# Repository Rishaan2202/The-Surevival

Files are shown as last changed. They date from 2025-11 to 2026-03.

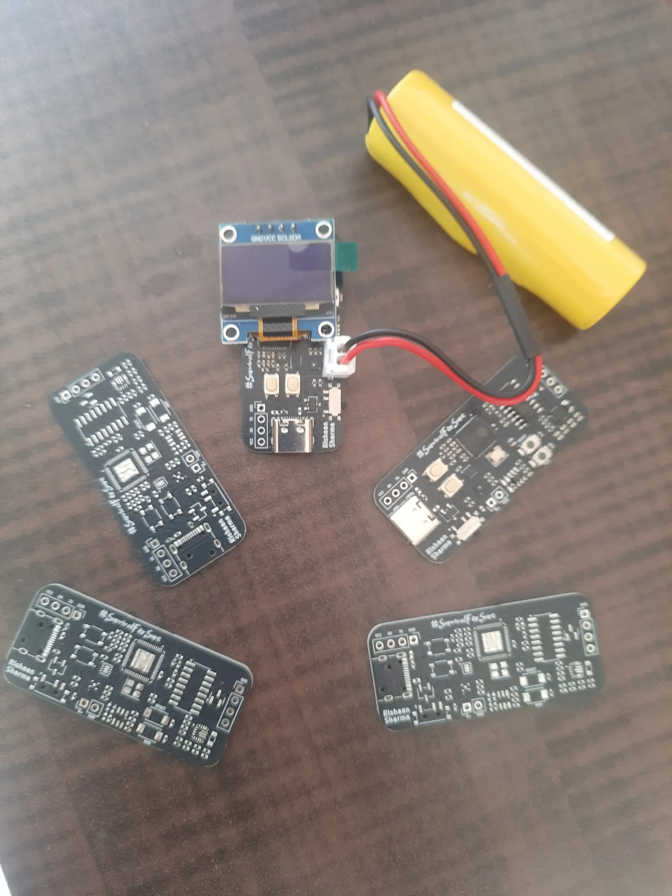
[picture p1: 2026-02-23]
20251218_154922.webp

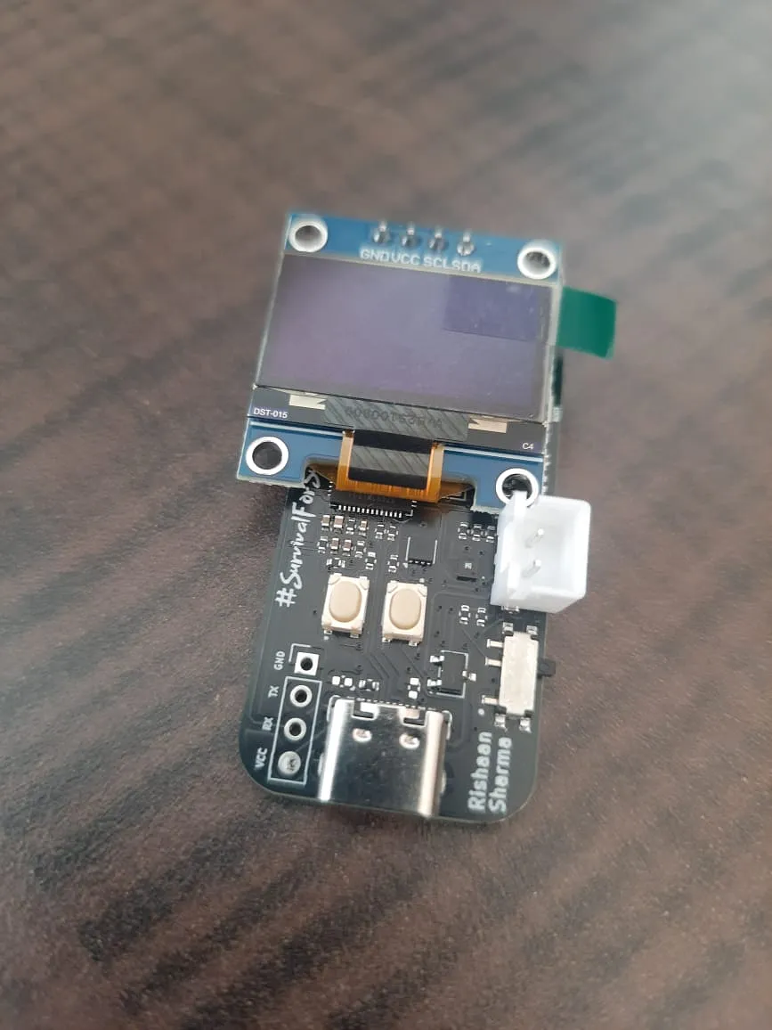
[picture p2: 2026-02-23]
image.webp

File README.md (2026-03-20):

# The-Surevival

<h2> Intro!!! </h2>
Yooo there!!! I am Rishaan Sharma, a 14 year old Indian. I made this project, 'The Surevival' as a project in hcb!
<br>
I have made this on KiCad, and yeah I'm a beginner! It's a very interesting project, which was attained after repetitive feilures, so please do check out for the Journal to know all that in detail!

<h2>OVERVIEW 🤔</h2>
So this is gonna be a project on a PCB, which is a PCBA (Yeah, cause I don't even have a soldering iron!), and yeah, It's my first PCB!!! It is basically a tool whose name suggests that it's a 'Survival Tool' (Sure + Survival = SUREVIVAL). Yeah, cool name rigth, ik! This is supposed to have a few features which are listed below! I have used the ESP32-S3FN8 as the MCU! and am having a Type-C input which is just for charging the battery! The 2000mAh Li-ion battery is gonna power up all the stuff like the load sensor, temp. sensor etc... So yeah, It's a cool thing and now take a look at it's features!!!

<h2>FEATURES ⚡️</h2>
1) GPS Tracking 
<br>
2) No. of Survival Dayzzz prediction using food! (My favorite)
<br>
3) Weather Monitoring
<br>
4) OLED Display!!! (For better UI)

<h2> THE SCHEMATIC </h2>

[The Surevival (2).pdf](https://github.com/user-attachments/files/23728820/The.Surevival.2.pdf)

<h3>It consists of 4 units, and These units further contain subunits which are lister below:</h3>
<br>

<h3>1) MCU!!! </h3>
<br>

<h3> 2) Power Management: </h3>
- Input Processing Unit (IPU) <br>
- Buck-Boost converter <br>
- Battery Charging Unit (BCU)
<br>

<h3> 3) Peripherals: </h3>
-Load Sensing Unit (Weight Sensor) <br>
- Switches (UI bro!) <br>
- GPS (ofc.) <br>
- Weather Monitoring Unit (WMU) <br>
- Display (OLED)
<br>

<h3>4) Crystal!</h3>
<br>

<h2>THE PCB</h2>

<h3> SO this is all the placement and routing stuff! It was really Time-Consuming!!! </h3>


<br>

<h3> idts that I need to explain a lot about the PCB, but yeah, I must compliment it's compactness, cause it's just 23mm*51mm </h3>
<br>
<br>

<h2>THE 3D Look (My fav!)</h2>

<h3> So yeah, I kinda like this part, cause it shows how would it be looking when it comes outside the screen (im in real world)! </h3>

<h3> Let's take a look at the one without much of the components, but with the OLED, which was placed by me on KiCad! </h3>


<br>


<br>

<h3> Now, let's see the one with all the components on it except the OLED and the GPS, which was produced by JLCPCB! </h3>
<br>



<h3> Yeah, that's so cool! I can't even believe that I made that! </h3>
<br>
<br>

<h2>THE BOM</h2>

<h3> Hmmm, so here is the tricky part! It took me many days to make this thing! I also tried to add a soldering kit to this, as I need that to put a few components on this, but then I came to know that I can't do that , so I removed that and now the BOM is $86.28 (JLCPCB) + $13.52 (Robocraze). Yeah I have 2 suppliers, one for PCBA and the other for some extra components which has $0 as it is originally from INDIA (As I am!) </h3>
<br>



<h3> Well, this doesn't contain the price of the PCBA products, but that will be clear by looking at this </h3>
<br>


<br>
<br>

<h2>Images</h2>
<br>
<h3>
  
  <br>
  
  <br>
  
  <br>
  
  <br>
</h3>

<h2>OUTRO!!!</h2>
<br>

Yeah, so this was the first PCB built by me, I have already made one before, but because of some unignorable things, I will need to redesign it. Well if you want to give any kinda comment regarding this project, then pls feel free to contact me. Here are my details:
<br>

Slack Username (Hackclub Workflow): @Rishaan
<br>
Email: rishaan.sharma2202@gmail.com

Pls don't forget to take a look at the journals! And also pls visit and follow this project on Blueprint here:
<br>

https://blueprint.hackclub.com/projects/210
<br>
<h2> TYSM 😊🙏 </h2>

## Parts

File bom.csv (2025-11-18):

Designator | Footprint | Quantity | Value | LCSC Part # | Robocraze | Value (in USD)
C1, C2 | 402 | 2 | 10pF | C32949
C12, C13, C14, C16, C25, C7 | 402 | 6 | 0.1uF | C1525
C15, C27, C28, C29 | 402 | 4 | 22uF | C105226
C17, C18, C19, C8 | 402 | 4 | 1uF | C52923
C23 | 402 | 1 | 4.7uF | C23733
C24, C26, C30, C31, C32, C6 | 402 | 6 | 10uF | C15525
D1, D2, D3 | 402 | 3 | LED | C30584803
IC1 | HSFPAR004A | 1 | HSFPAR004A | C470800
J1 | PinHeader_1x02_P2.54mm_Vertical_JST | 1 | Battery Connectors |  | 2.54mm pitch 2 pin JST Cable with Connector | 0.73
J2, J3 | PinHeader_1x04_P2.54mm_Vertical_Female | 1 | Conn_01x04 |  | 40x1 Female Berg Strip | 0.1
J5 | AMPHENOL_10155435-00011LF | 1 | USB Type-C Input | C2765186
L1 | 805 | 1 | 1.5uH | C216155
Q1 | SOT-23 | 1 | SS8550 | C727138
R1 | 402 | 1 | 220Ω | C25091
R10, R12 | 402 | 2 | 1kΩ | C11702
R11 | 402 | 1 | 2kΩ | C4109
R14, R21 | 402 | 2 | 100kΩ | C25741
R15 | 402 | 1 | 470kΩ | C427225
R16 | 402 | 1 | 150kΩ | C2909320
R17, R24, R25, R30, R31, R32, R33, R34, R35, R36, R37 | 402 | 11 | 10kΩ | C25744
R2, R3 | 402 | 2 | 5kΩ | C5948099
R20 | 402 | 1 | 100Ω | C25076
R26, R27 | 402 | 2 | 22Ω | C25092
R28, R29 | 402 | 2 | 5.1kΩ | C25905
R5, R6, R8, R9 | 402 | 4 | 4.7kΩ | C25900
S1, S2 | SW_SKRPACE010 | 2 | SKRPACE010 | C139797
S3, S4 | Push Button | 2 | TS-1088-AR02016 | C720477
SW1 | SW_PCM12SMTR | 1 | PCM12SMTR | C221841
U1 | SOT-23-3L_AOS | 1 | AO3401A | C15127
U10 | VREG_TPS63070RNMR | 1 | TPS63070RNMR | C109322
U3 | WSON-8-1EP_2x2mm_P0.5mm_EP0.9x1.6mm_ThermalVias | 1 | TMP1075DSG | C2870250
U4 | ESP32-S3FN8 | 1 | ESP32-S3FN8 | C2913196
U5 | Crystal_SMD_3225-4Pin_3.2x2.5mm | 1 | SMD3225 | C5444549
U6 | SOP-16_3.9x9.9mm_P1.27mm | 1 | HX711 | C6705483
U9 | SOT23-6 | 1 | TP4057 | C725791
J6 | PinHeader_1x04_P2.54mm_Vertical_Male | 1 |  |  | 40x1 Pin 2.54mm Pitch Male Berg Strip | 0.056
Display1 | OLED Display | 1 |  |  | 0.96 Inch OLED Display Module SPI/I2C 4pin Blue Color | 3.52
GPS1 | GPS | 1 |  |  | Ublox Neo-6M GPS Module With EEPROM | 5.39
B1 | Li-ion Battery | 1 | Battery |  | Witty Fox 3.7V 2000 mAh Li-ion GPS Cylindrical Battery | 3.41
 |  |  |  |  |  | 13.206

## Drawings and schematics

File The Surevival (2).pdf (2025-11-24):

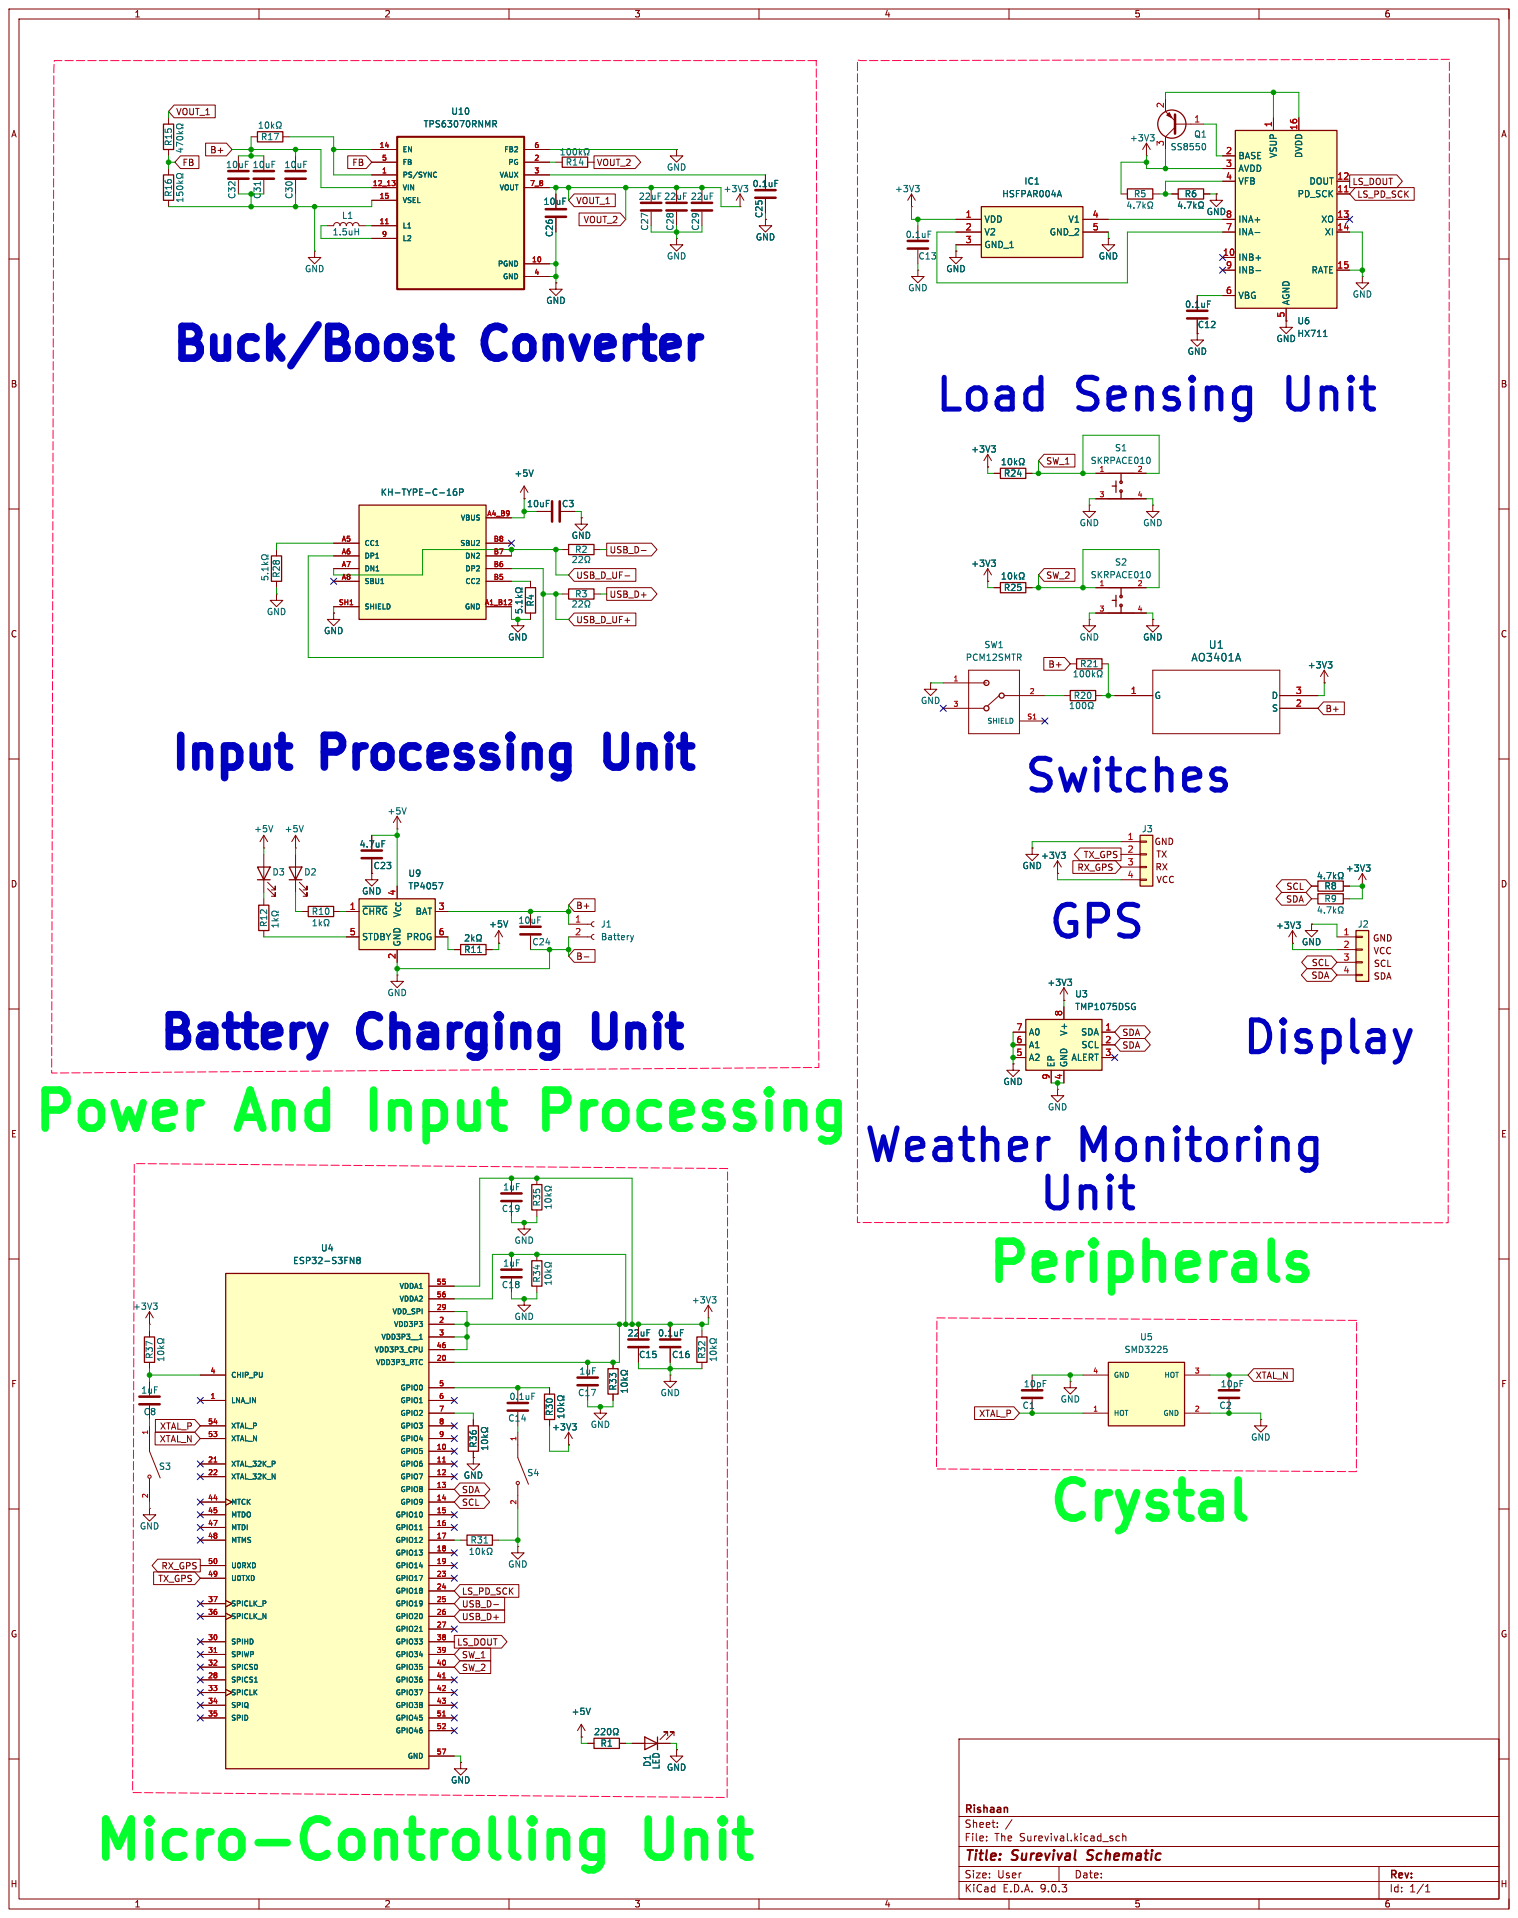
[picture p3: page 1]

5 DVDD 16 DOUT 12 PD_SCK 11 XO 13 XI 14 RATE 15 GND GND

5 DVDD 16 DOUT 12 PD_SCK 11 XO 13 XI 14 RATE 15 U6 HX711 +3V3

4 SDA 1 SCL 2 ALERT 3 +3V3 GND GND

2 BAT 3 PROG 6 U9 TP4057 GND R12 þÿ1k©

4 SDA 1 SCL 2 ALERT 3 U3 TMP1075DSG R30 C14 þÿ10k© 0.1uF

Battery Charging Unit
Power And Input Processing

Id: 1/1 Title: Surevival Schematic

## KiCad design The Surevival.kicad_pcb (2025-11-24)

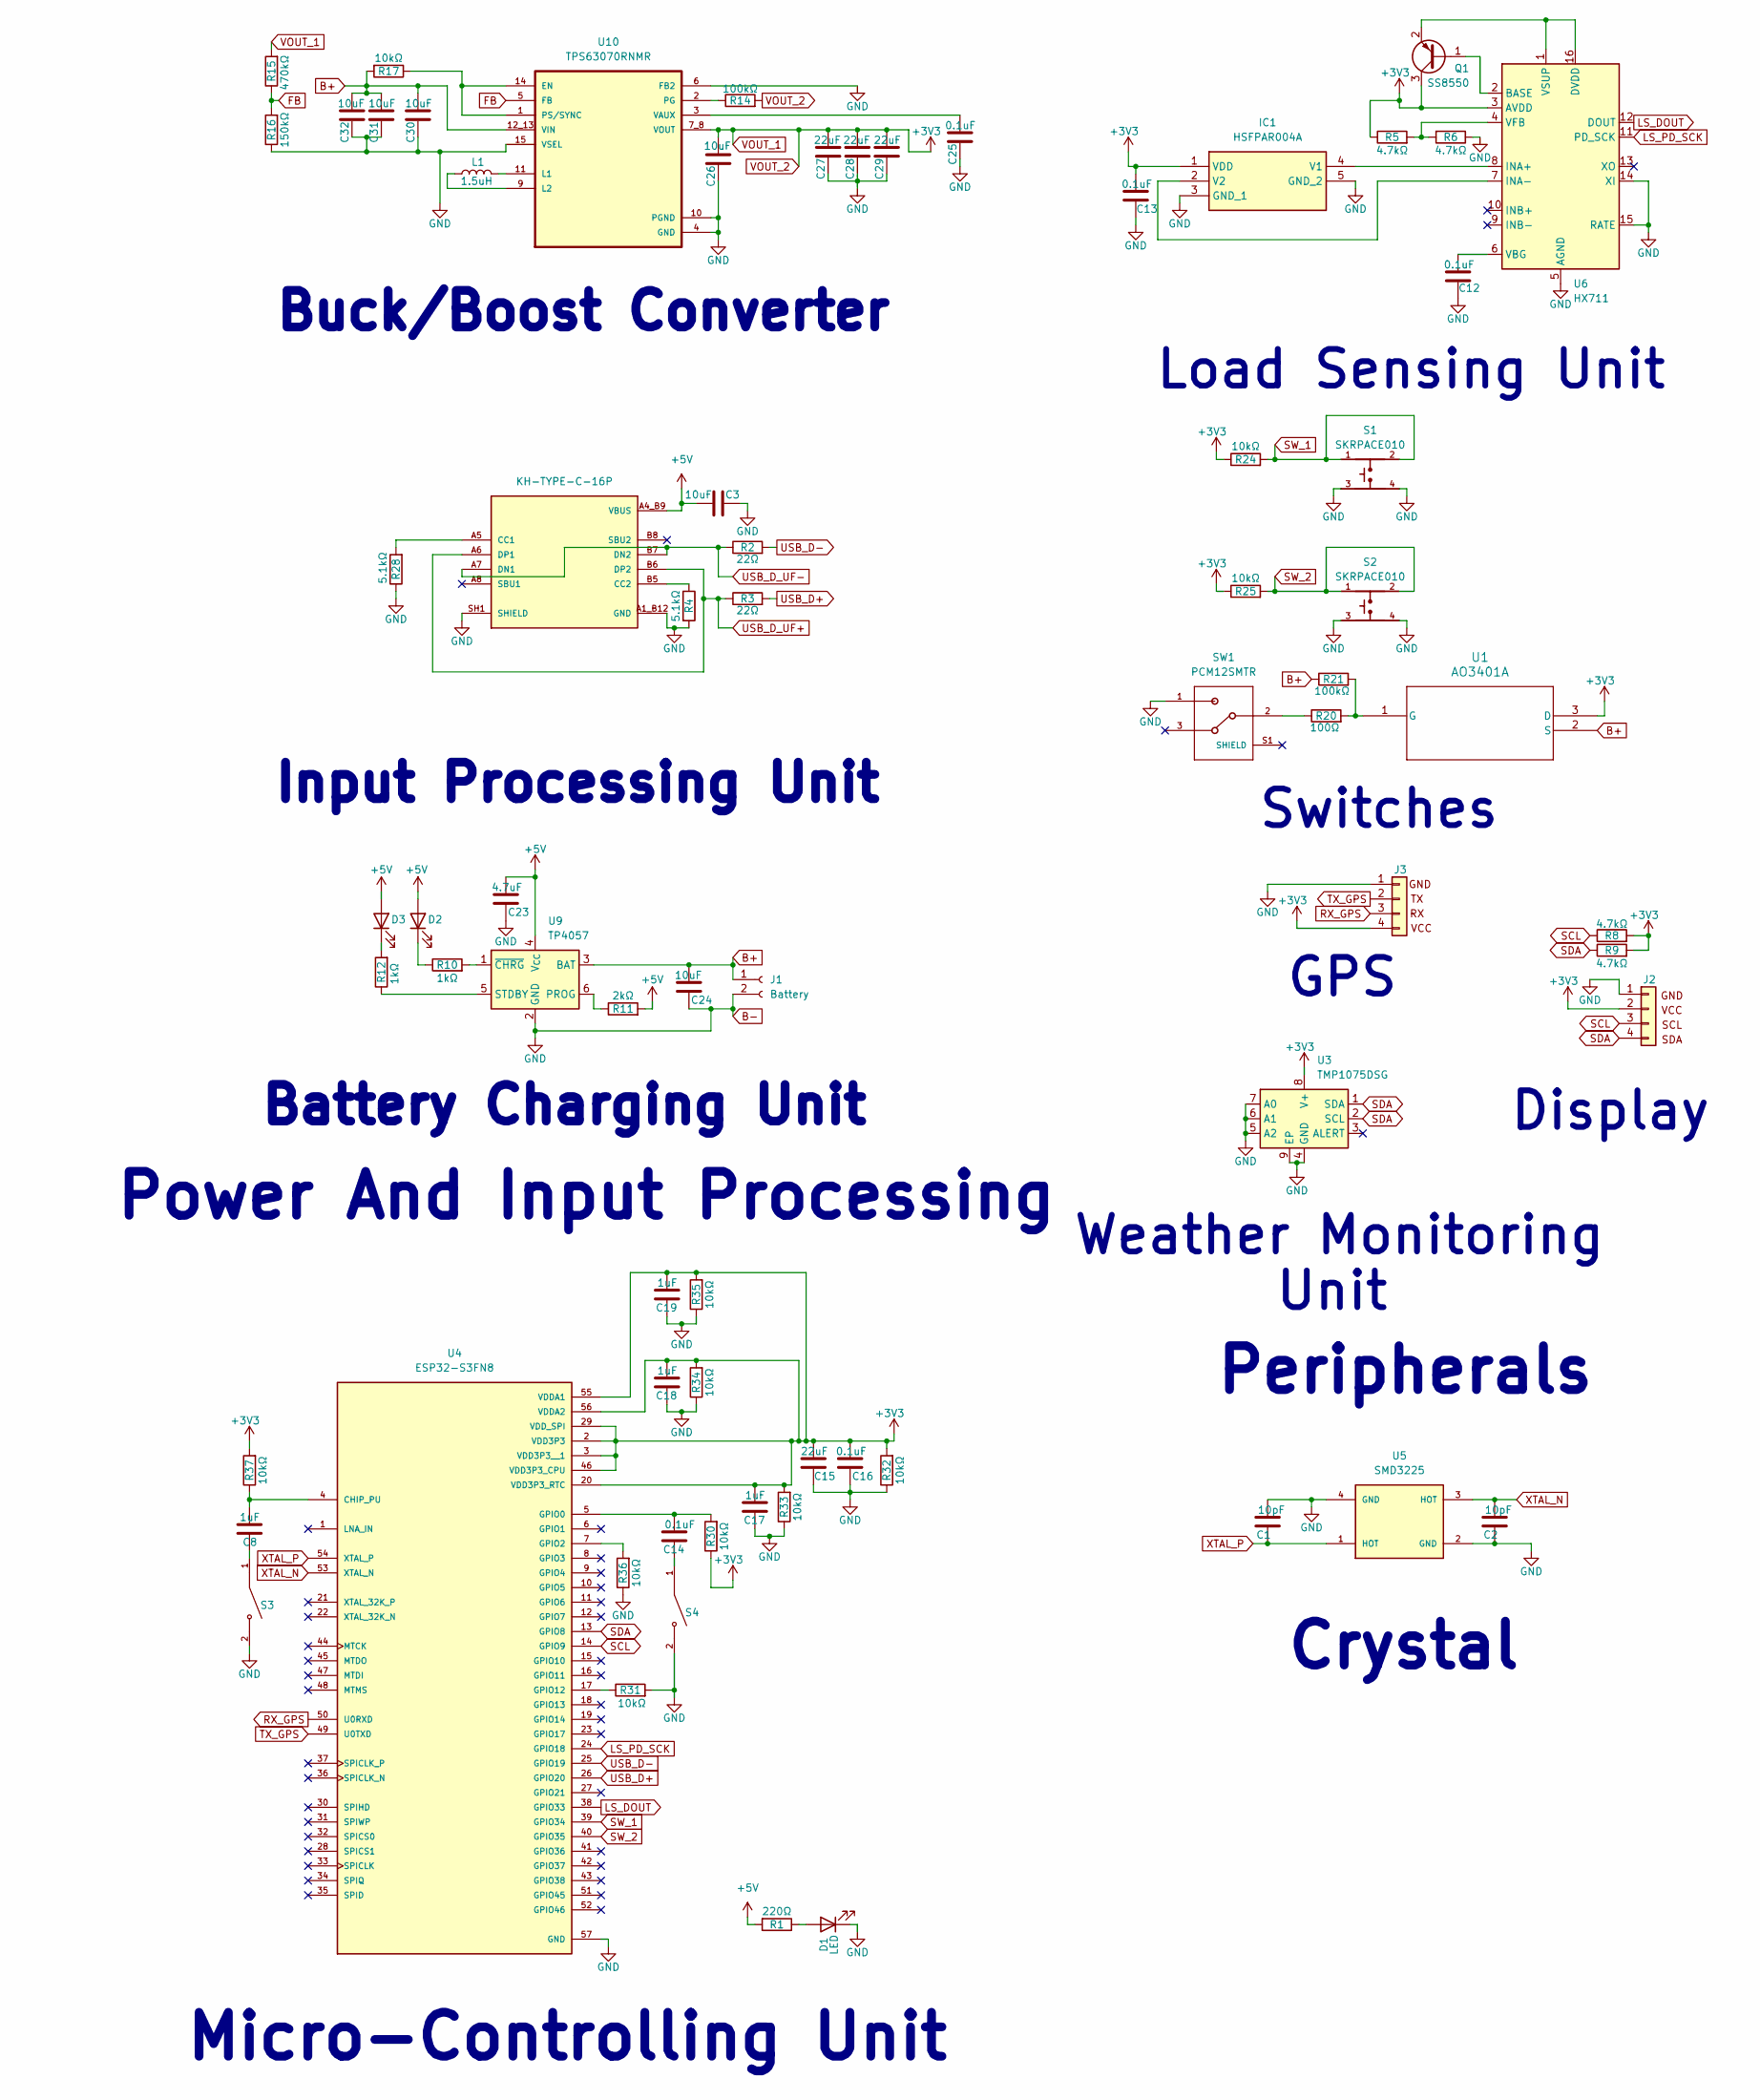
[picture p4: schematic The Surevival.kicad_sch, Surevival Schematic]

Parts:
C1, C2: 10pF; C_0402_1005Metric
C3, C24, C26, C30, C31, C32: 10uF; C_0402_1005Metric
C8, C17, C18, C19: 1uF; C_0402_1005Metric
C12, C13, C14, C16, C25: 0.1uF; C_0402_1005Metric
C15, C27, C28, C29: 22uF; C_0402_1005Metric
C23: 4.7uF; C_0402_1005Metric
D1, D2, D3: LED; LED_0402_1005Metric
IC1: HSFPAR004A; Mouser Part Number 688-HSFPAR004A
J1: Battery; PinHeader_1x02_P2.54mm_Vertical
J2, J3: Conn_01x04; PinHeader_1x04_P2.54mm_Vertical
J6: KH-TYPE-C-16P; KINGHELM_KH-TYPE-C-16P; PARTREV A0
L1: 1.5uH; L_0805_2012Metric
Q1: SS8550; SOT-23
R1: 220Ω; R_0402_1005Metric
R2, R3: 22Ω; R_0402_1005Metric
R4, R28: 5.1kΩ; R_0402_1005Metric
R5, R6, R8, R9: 4.7kΩ; R_0402_1005Metric
R10, R12: 1kΩ; R_0402_1005Metric
R11: 2kΩ; R_0402_1005Metric
R14, R21: 100kΩ; R_0402_1005Metric
R15: 470kΩ; R_0402_1005Metric
R16: 150kΩ; R_0402_1005Metric
R17, R24, R25, R30, R31, R32, R33, R34, R35, R36, R37: 10kΩ; R_0402_1005Metric
R20: 100Ω; R_0402_1005Metric
S1, S2: SKRPACE010; SW_SKRPACE010
S3, S4: TS-1088-AR02016; Push Button; PARTREV N/A
SW1: PCM12SMTR; SW_PCM12SMTR
U1: AO3401A; SOT-23-3L_AOS
U3: TMP1075DSG; WSON-8-1EP_2x2mm_P0.5mm_EP0.9x1.6mm_ThermalVias
U4: ESP32-S3FN8
U5: SMD3225; Crystal_SMD_3225-4Pin_3.2x2.5mm
U6: HX711; SOP-16_3.9x9.9mm_P1.27mm
U9: TP4057; SOT23-6
U10: TPS63070RNMR; VREG_TPS63070RNMR

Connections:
+5V: C3.1, C23.1, D2.2 (A), D3.2 (A), J6.A4_B9 (VBUS), J6.A9_B4 (VBUS), R1.2, R11.2, U9.4 (V_{CC})
B+: C24.1, C30.2, C31.2, C32.2, J1.1, R17.2, R21.1, U1.2 (S), U9.3 (BAT), U10.12_13 (VIN)
B-: C1.1, C2.2, C3.2, C12.2, C13.2, C15.2, C16.2, C17.2, C18.2, C19.2, C23.2, C24.2, C25.1, C26.1, C27.1, C28.1, C29.1, C30.1, C31.1, C32.1, D1.1 (K), IC1.3 (GND_1), IC1.5 (GND_2), J1.2, J2.1, J3.1, J6.A1_B12 (GND), J6.A12_B1 (GND), J6.SH1 (SHIELD), J6.SH2 (SHIELD), J6.SH3 (SHIELD), J6.SH4 (SHIELD), R4.2, R6.1, R16.1, R28.1, R31.2, R32.1, R33.1, R34.1, R35.1, R36.1, S1.3, S1.4, S2.3, S2.4, S3.2, S4.2, SW1.1, U3.4 (GND), U3.5 (A2), U3.6 (A1), U3.7 (A0), U3.9 (EP), U4.57 (GND), U5.2 (GND), U5.4 (GND), U6.5 (AGND), U6.14 (XI), U6.15 (RATE), U9.2 (GND), U10.4 (GND), U10.6 (FB2), U10.10 (PGND), U10.15 (VSEL)
FB: R15.1, R16.2, U10.5 (FB)
LS_DOUT: U4.38 (GPIO33), U6.12 (DOUT)
LS_PD_SCK: U4.24 (GPIO18), U6.11 (PD_SCK)
unnamed: C8.2, S3.1
unnamed: C14.2, S4.1
unnamed: D1.2 (A), R1.1
unnamed: D2.1 (K), R10.1
unnamed: D3.1 (K), R12.2
unnamed: IC1.4 (V1), U6.8 (INA+)
unnamed: IC1.2 (V2), U6.7 (INA-)
unnamed: J6.A5 (CC1), R28.2
unnamed: J6.B5 (CC2), R4.1
unnamed: Q1.1 (B), U6.2 (BASE)
unnamed: Q1.2 (E), U6.1 (VSUP), U6.16 (DVDD)
unnamed: R20.1, SW1.2
unnamed: R20.2, R21.2, U1.1 (G)
unnamed: C8.1, R37.1, U4.4 (CHIP_PU)
unnamed: C14.1, R30.2, U4.5 (GPIO0)
unnamed: R36.2, U4.7 (GPIO2)
unnamed: R31.1, U4.17 (GPIO12)
unnamed: C12.1, U6.6 (VBG)
unnamed: R5.2, R6.2, U6.4 (VFB)
unnamed: R11.1, U9.6 (PROG)
unnamed: R12.1, U9.5 (STDBY)
unnamed: R10.2, U9.1 (~CHRG)
unnamed: R17.1, U10.1 (PS/SYNC), U10.14 (EN)
unnamed: L1.2, U10.11 (L1)
unnamed: L1.1, U10.9 (L2)
unnamed: R14.1, U10.2 (PG)
unnamed: C25.2, U10.3 (VAUX)
RX_GPS: J3.3, U4.50 (U0RXD)
SCL: J2.3, R8.1, U4.14 (GPIO9)
SDA: J2.4, R9.1, U3.1 (SDA), U3.2 (SCL), U4.13 (GPIO8)
SW_1: R24.2, S1.1, S1.2, U4.39 (GPIO34)
SW_2: R25.2, S2.1, S2.2, U4.40 (GPIO35)
TX_GPS: J3.2, U4.49 (U0TXD)
USB_D+: R3.2, U4.26 (GPIO20)
USB_D-: R2.2, U4.25 (GPIO19)
USB_D_UF+: J6.A6 (DP1), J6.B6 (DP2), R3.1
USB_D_UF-: J6.A7 (DN1), J6.B7 (DN2), R2.1
VOUT_1: C13.1, C15.1, C16.1, C17.1, C18.1, C19.1, C26.2, C27.2, C28.2, C29.2, IC1.1 (VDD), J2.2, J3.4, Q1.3 (C), R5.1, R8.2, R9.2, R14.2, R15.2, R24.1, R25.1, R30.1, R32.2, R33.2, R34.2, R35.2, R37.2, U1.3 (D), U3.8 (V+), U4.2 (VDD3P3), U4.3 (VDD3P3__1), U4.20 (VDD3P3_RTC), U4.29 (VDD_SPI), U4.46 (VDD3P3_CPU), U4.55 (VDDA1), U4.56 (VDDA2), U6.3 (AVDD), U10.7_8 (VOUT)
XTAL_N: C2.1, U4.53 (XTAL_N), U5.3 (HOT)
XTAL_P: C1.2, U4.54 (XTAL_P), U5.1 (HOT)

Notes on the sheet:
Unit
Switches
Battery Charging Unit
Peripherals
Buck/Boost Converter
GPS
Power And Input Processing
Micro-Controlling Unit
Input Processing Unit
Weather Monitoring
Load Sensing Unit
Display
Crystal

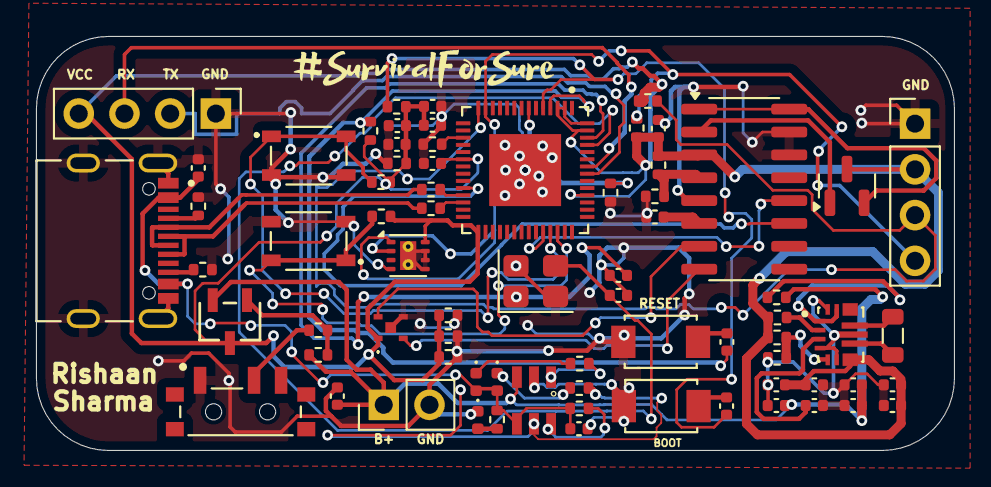
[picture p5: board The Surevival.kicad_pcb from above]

Board: 2 copper layers, 51.0 x 23.0 mm, 72 parts (0 on the bottom side), 46 nets.

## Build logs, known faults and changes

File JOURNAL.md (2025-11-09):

<!--
  ===================    !!READ THIS NOTICE!!   ====================
  DO NOT edit this file manually. Your changes WILL BE OVERWRITTEN!
  This journal is auto generated and updated by Hack Club Blueprint.
  To edit this file, please edit your journal entries on Blueprint.
  ==================================================================
-->

## 10/7/2025 - Day 1! LET'S BEGIN!!!  

Yooo!!! so it's the Day 1 and I have started making this ultimate Survival tool! I have decided the ESP32 as the MCU. I also have a few other components in my mind, like BME280, load sensors etc. I have started making a schematic on KiCad and have already added the ESP32 in it. I thought that the ESP32-S3 was not available in LCSC, but I found ESP32-WROOM-32E-N4 in stock on LCSC! I changed the MCU with it and I also added a BME280 to the schematic. Take a look at the schematic:-



## 10/12/2025 11:51 AM - Day-2! Progress!!  

So I did the USB Type-C power input connection today for my ESP. I took help from the 'Custom Devboard' guide and the ESP32 datasheet for this, but I can't figure out where to connect the D+ and D- pins! but don't worry, I'll do something for them! Take a look at the Schematic now:-



## 10/12/2025 11:53 AM - Day-3! Even more progress!!!  

Yeah! You see the schematic, it doesn't look like a day 3 schematic but yeah, it is! So today I tried to search for the Load sensors, but couldn't find any SMD one, so I will think upon it. I also tried to figure out that D+ and D- pin thingy, but couldn't come to any conclusion. So I asked for it on #electronics. I hope to get some answers on that. The major thing done today is the connection for BME280 sensor!!! Yeah, it's a great achievement for me!:-



## 10/14/2025 9 PM - Day 4! Done with the USB-to-UART thing!!!  

I did it! One of my friend (Teammate in another project) told me that I had to use the USB to UART feature for the transmission of Data between the MCU and the coding Device via the Type-C port. After this, my D+ and D- problem came to an end, and I used the CP2102 USB-to-UART converter for this (As my friend suggested this). I also kinda engulfed some stuff inside those boxes for my schematic to look more systematic and organized (and yeah, cooler!). Look at the schematic now:- 



## 10/14/2025 10 PM - Day 5! Found The Load Sensor!!!  

Yooo!!! So today I was just searching for Load sensors on LCSC, and I found one perfect fit, I mean so perfect for my application, that I just loved it! So when I was goin' through its Datasheet, I found that for that I'll also need an AC-to-DC converter! Then I searched a bit and also found a perfect one for the project, but I kinda struggled to understand why there were different 'pin namings' in the datasheet of both the components. Well, these all things for finding the components, importing symbols and footprints took 30 mins!!! Here's the Schematic for now:-


## 10/15/2025 - Day 6! Added a COMPASS!!!  

Hi Guyzzz!!!, so today I did much work. You can see that the load sensor is done in the schematic, well It was the most difficult part of the schematic! But wait! is there something called the 'Magnetic Field Sensing Unit' in the schematic??? Well, YEAH IT IS!!! I have added a very small 2*2mm compass kinda thing to my schematic, and yeah it is cool. This would be used for navvigation.



## 10/17/2025 - Day 7! Added the SCREEN!!!  

Well today I searched up the whole internet just to find a good GPS and a display for my purpose, but unfortunately I wasn't able to find the GPS, but I found the Display! It is the EA_DOGS164W-A. I did all the Display connections, but the footprint is yet to be added, I'll think upon the GPS thingy later on... Well the schematic looks like this for now!
  

## 10/18/2025 - Day 8! Display Changed!!!  

Yooo! so I kinda changed the Screen. Yeah, I kinda didn't like that one, so I chose this one and I have this from Digikey. Now I have to order from both LCSC and digikey!!! This means that double shipping fee! But there was no option LCSC just had only 4-5 screens, and those were also not good, so I had to do this. Well the screen's symbol looks like this:-


## 10/19/2025 - Day 9! Some Planning Stuff!!!  

Yoo there! so motivation increased after peeking into the TOOLBAG!!! So yeah, I worked during my holidays,even when I'm 800 Km away from my laptop. Yeah, kinda hard working boy!👷‍♂️👷‍♂️. So here is something called the Surevuval Plan (maybe survival plan too). It has a cool SUREVIVAL logo! (designed by me) and it all tells about the current model of the project as well as the future ones. Don't forget to take a quick look at thi thing which tood more than 30 min to be made!

  

## 10/20/2025 - Day 10! Watched a bit TUTORIALS!!!  

Happy Diwali To All!!! It's kinda biggest festival celebrated in India! So today I watched a bit tutorials on YouTube about the ESP 32 chip and a few of it's peripherals. I wonder what could be the i.age for today!

  

## 10/21/2025 - Day 11! Edited the README.md!!!  

So today I did some changes in the README.md, cause I needed my project to be a tier 1, so this has to be there for polishing it and it took quite a lot of time!!!

  

## 10/26/2025 - Day 12! So here's #ThePlan!!!  

I kinda made a plan, yeah I'm kinda used to make plans after making much of the schematic! ik that's not good, but josh doesn't come with asking! I have decided that I'll be making more than one versions of 'The Surevival'. This is the version 0 (v0) with the least features, which are:-

1) GPS Tracking
2) Estimated lasting of Food and H2O!
3) SurvivO'meter (Kinda prediction of no. of Survival dayzzz!!!

Yeah, ik I revised them, but this was to be done as I am making another project parallely, pls understand the burdening me!!!

Here's the historic #ThePlan-
  

## 10/28/2025 - Day 13! DONE with the SCHEMATIC!!!  

Yeah!!! So I completed the SCHEMATIC! Hooray! (Nearly 4h work). IDTS that I should be this much happy, but I have completed the schematic within just 13th day of my building! This is a big achievement for me. btw, I also took a harsh decision! And it is that I am gonna use the GPS Neo 6M module and gonna hand solder it, as it is kinda difficult for me design the RF thingy on my board for the antennas myself! I also came to know that the GPS used the UART interphase, which let me add the weather monitoring sensor (BME280) onto my board again! Well I also made the schematic look good by sophisticating and arranging all the stuff and also made the values of each component on my Schematic visible, which I hid before, cause I thought that it was ruining the look of my Schematic, but now I came to know that 'Understandability' is also a factor which shouldn't be ignored by me!!! Now take a look at the Schematic:-


It has been divided into 3 sub-parts, The first one is all the Power related stuff including the battery and it's charger:-


The second part is of the MCU:-


And the last is the main thing which contains all the sensors:-


I hope you liked the schematic, I also asked for review for this an #blueprint on slack! and got some very helpful replies like absence of pull ups for I2C, See this:-


## 10/29/2025 - Day 14! THE FAILURE DAY!!!  

Well, today!!! tbh, it was really non-frustating, interesting and hopeful day! (SARCASM ALERT!!!) I kinda did the footprint of all the components except the Switches and buttons (Yeah I kinda added them today cause they were missing!). I was able to find a good switch for me after so much time, but I didn't have access to its EDA models of KiCad version. I was very tired, but I didn't lose hope! (That's the Spirit). Then I thought to try EasyEDA2KiCad! So, I saw the guide on the Highway website and, IT BLEW MY MIND!!! Bro! I'm not a software guy. So, then I kinda wasted my entire left time arguing with Chat GPT! I also got my cmd full of errors! And yeah Terminal too! So, I thought, that LET'S RETIRE FOR THE DAY!!!

  

## 10/30/2025 - Day 15! Finally STARTED THE PCB!!!  

So today I quickly attempted to find good switches, and yeah found them with their footprints and symbols (Feels like HEAVEN)! I added two pushbuttons connected to 2 GPIOs which would indicate any answer of the user for the thing asked on the screen (They are kinda YES/NO switches). Then, I quickly asked Chat GPT about a few pins on my ESP32 and then BOOM! SCHEMATIC-->PCB!!! At first, I saw something like this:-



Then I thought to BLAST OFF this Battery holder and get a smaller battery, cause literally the Battery holder was bigger than the Entire PCB itself! So, I kept it aside and did the Input stuff and here's the result!

  

## 10/31/2025 - Day 16! ROUTING GUYZ!!!  

Hmmm! idts that there is much to tell today, cause today I just ROUTED! Well I also got the 3D model of my ESP32 and could fix it on position after facing a GLITCH! (idk what happened, but the X and Y axis kinda did the same thing). Well, I have asked 'THE LEARNED PEOPLE' on slack to comment on my design on #electronics and am waiting for their helpful replies! Well here is the design which I showed them!

  

## 11/1/2025 - Day 17! PCB DONE!!! (kinda)  

Hi!!! Do you remember the routing that you saw in the yesterday's journal entry? It was not so cool ig. And I also thought that the project was also not planned properly, so today I did this:-



Yeah! I kinda drew the approx. sizes of all the components, so that I can decide how to place them. Now, see this:-



This was supposed to be the placement of all the components! Wait!!! Did I just say 'WAS'? Yup, I did! While I was designing the PCB, I kinda changed the placement of a few components and then I routed mostly the whole PCB and finally here was the output!



And the thing which looks the best is yet to come, and that's the 3D MODEL!!!



The whole PCB is mostly done, just the thing which I need to add is that I need to add a connector for the battery and have to remove the switch which was connected to the MCU! So yeah, that's for today! Have a great day!!!  

## 11/4/2025 12 AM - Day 18! Did the ROUTING of Diff. pairs!!!  

Hiii all! So today was also kinda a normal day. I did the routing of the differential pairs, cause I came to know that the length of their traces MUST be LENGTH ALLINGNED!!! So I struggled the entire day and kinda ruined the traces near the Type C input! Then it took a lot of time of mine to fix it! I also tried to add some of the 3D models, but failed to do so due to my hectic schedule!!! I also changed the size of the PCB from 33cm*48cm to 35cm*50cm!

  

## 11/4/2025 6 PM - Day 19! Started The BOM Thing!!!  

Yeah!!! Finally I'm done with the PCB! Yeah you heard it right, it's done! I added the connector for my battery, did that diff. pair stuff and also removed one unnecessary switch! After this the PCB's done and here's the Final look! WAIT!!! I just remembered something! I forgot to add some cool text and images to the silkscreen! Well I'll do that later, It looks like this for now:-



Well, adding 3D models is a time consuming thing, so I'll do that later. Here's the 3D thing of SUREVIVAL:-



Wait! It isn't over yet, I also starter the BOM!!!

  

## 11/5/2025 - Day 20! The SILKY DAY (Silkscreen work)!!!  

OMG!!! Today, I just did the work for the looks of the PCB and did all the things just at the back layer (Cause front is kinda populated and chaotic!) I did a bit of designing (Finally! Something in which I'm good at!) with Canva, used the image converter of KiCad, and BOOM!!! Here is the Final output!



It looks SOOOOOOO COOL!!!  

## 11/6/2025 - Day 21! 'NOT SO GOOD' day!!!  

Guyzzz! Something BAD just happened. Lemme tell you. First I sat and started looking for some 3D models, after finding and placing a few of them. (Well the GPS is kinda upside down, let it be for now!)



Then I started to finish my BOM (It took a quite lot of time)!



Then I made my cart and reached the First step of ordering! (Ofc. I can't order cuz I don't have grant till now). I was shocked to see the price of the PCB! It was just $22.26 for one PCB inc. Shipping fee!!!



Then I did the JLCPCB thing from where I was getting the PCB for $2! I selected the PCBA option and then read each instruction and saw that min. PCBs required were 2! Then I changed my Cart in LCSC and did QUANTITY*2. I was shocked, cause I got $5 coupon!!! And the total for 2 PCBs was just $31.56!!!



Kinda crazy! right? But then came that 'Something BAD' thing! I saw that min. size of a PCB for PCBA was 70mm (Heavy Sob*∞)!!! I was kinda brocken from inside and am now waiting for the reply of other Hack clubbers on SLACK!!!

## 11/7/2025 - Day 22! The RUINING of my QUOTE!  

Ughhh!!! It didn't go well! Today I changed the PCB from standard PCBA to Economic one. Then I became very happy and thought that I would rapidly reach be in the final part of ordering, but something really terrible happened!!! You might be wondering what? SO the thing is this:



2 parts are only available in STANDARD!!! You might think that2 components are not a great deal, I can change that easily, BUT see this too:



Those 2 components include the very MCU of the Board!!! I can't do all this again, so I've asked for help in Slack, let's see what the people would suggest me to do!!!

## 11/8/2025 - Day 23! The COMEBACK!!!  

Today! I did all the connections of my new MCU!!! Yup, you heard it right, all the ones! Well except external crystal ig, as suggested by Chat GPT. I also removed the USB-UART thing, cause now I can directly connect D+ and D- to the MCU pins, thanks to my new MCU (ESP32-S3FN8)! So ig that might be enough for today, tmr I'll see the thing for the weather monitoring sensor. Huhhhh! What a difficult think building a PCB is!!!



## 11/9/2025 - Day 24! PCB, Again?  

So today I did the new schematic with the new MCU and a new temp. and humidity sensor too! and it looks nice! (For now).



I also started the PCB and saw that the new MCU is very small, YAY!!! But, no need to be happy, cause you also gotta see this:



Yeah, I kinda messed the PCB part again! Now It would take 1-2 days more for the PCB to be completed. The BOM is already there, just need to change the MCU and the Temp. sensor in that, and then hopefully I can submit this thing!!!
